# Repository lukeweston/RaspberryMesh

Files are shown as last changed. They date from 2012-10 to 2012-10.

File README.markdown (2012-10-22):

**Raspberry Pi sensor / power supply / LCD / 802.15.4 mesh network expansion board**   
Luke Weston, 2012     

Released as Open Hardware under the CERN Open Hardware License - http://ohwr.org/cernohl  

This Raspberry Pi add-on daughterboard or shield incorporates a 16x2 alphanumeric LCD display (standard HD44780-type display), a visible light sensor, a barometric pressure
and temperature sensor, a smal RGB LED for visual output, and an Atmel ATmega128RFA1 AVR microcontroller with integrated IEEE 802.15.4 mesh network transceiver with support
for IPv6/6LoWPAN. 

A real-time clock with battery backup and a buck-converter voltage regulator allowing a wide input voltage range between 7 and 35 volts to power the Raspberry Pi are also
included. Voltages up to 35V can simply be plugged into the 2.1mm power jack to power the entire system flexibly.

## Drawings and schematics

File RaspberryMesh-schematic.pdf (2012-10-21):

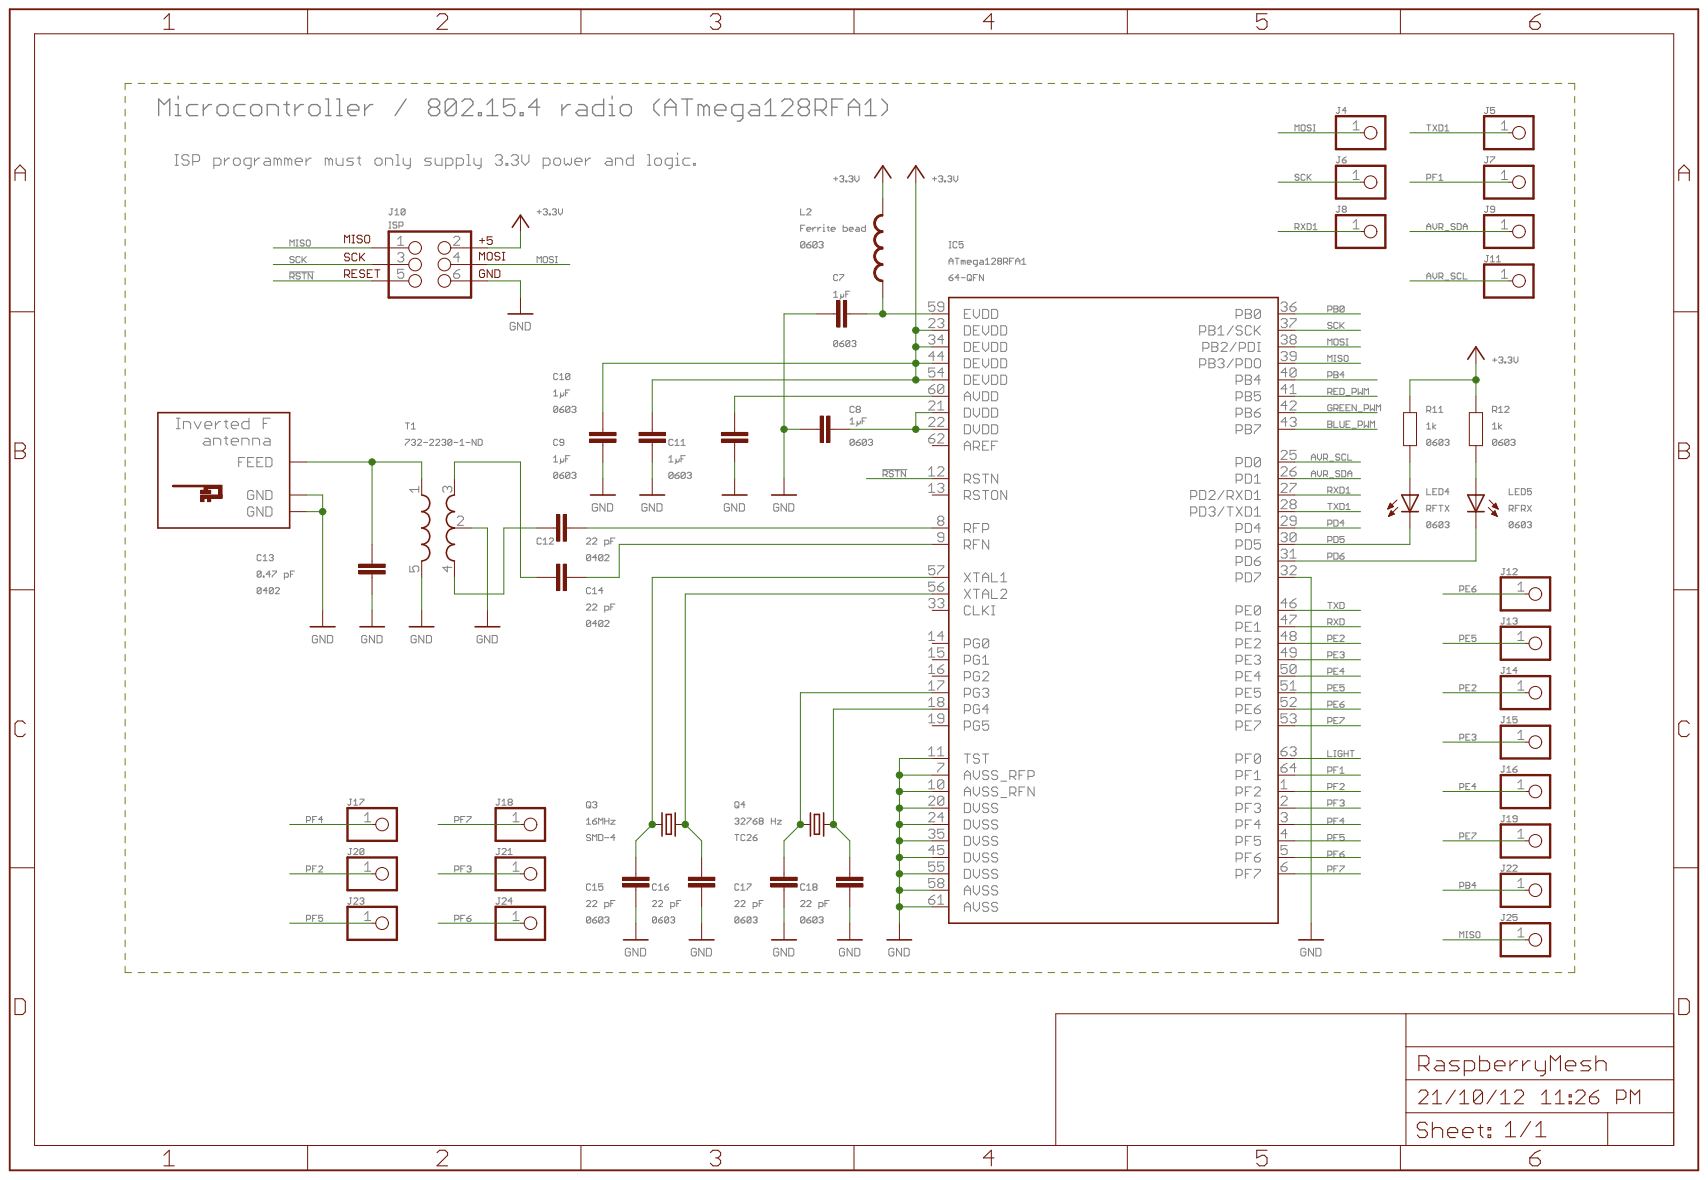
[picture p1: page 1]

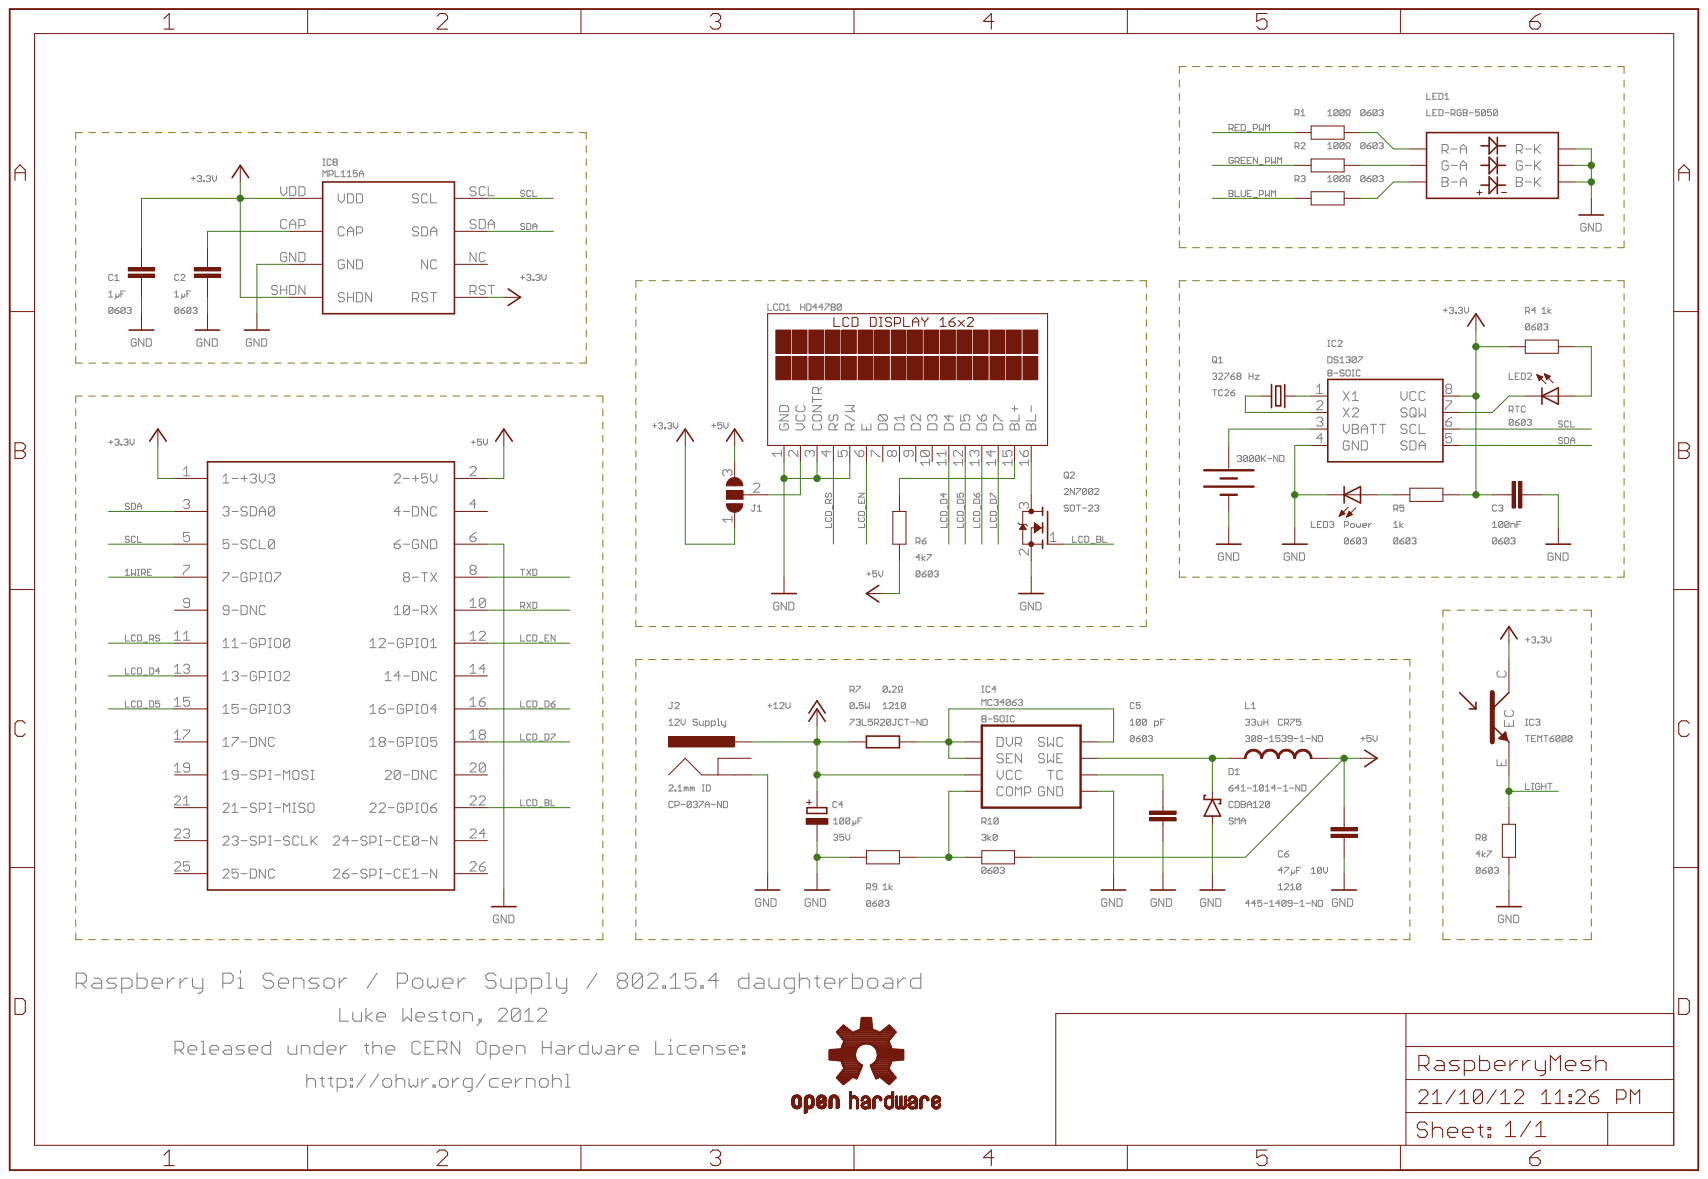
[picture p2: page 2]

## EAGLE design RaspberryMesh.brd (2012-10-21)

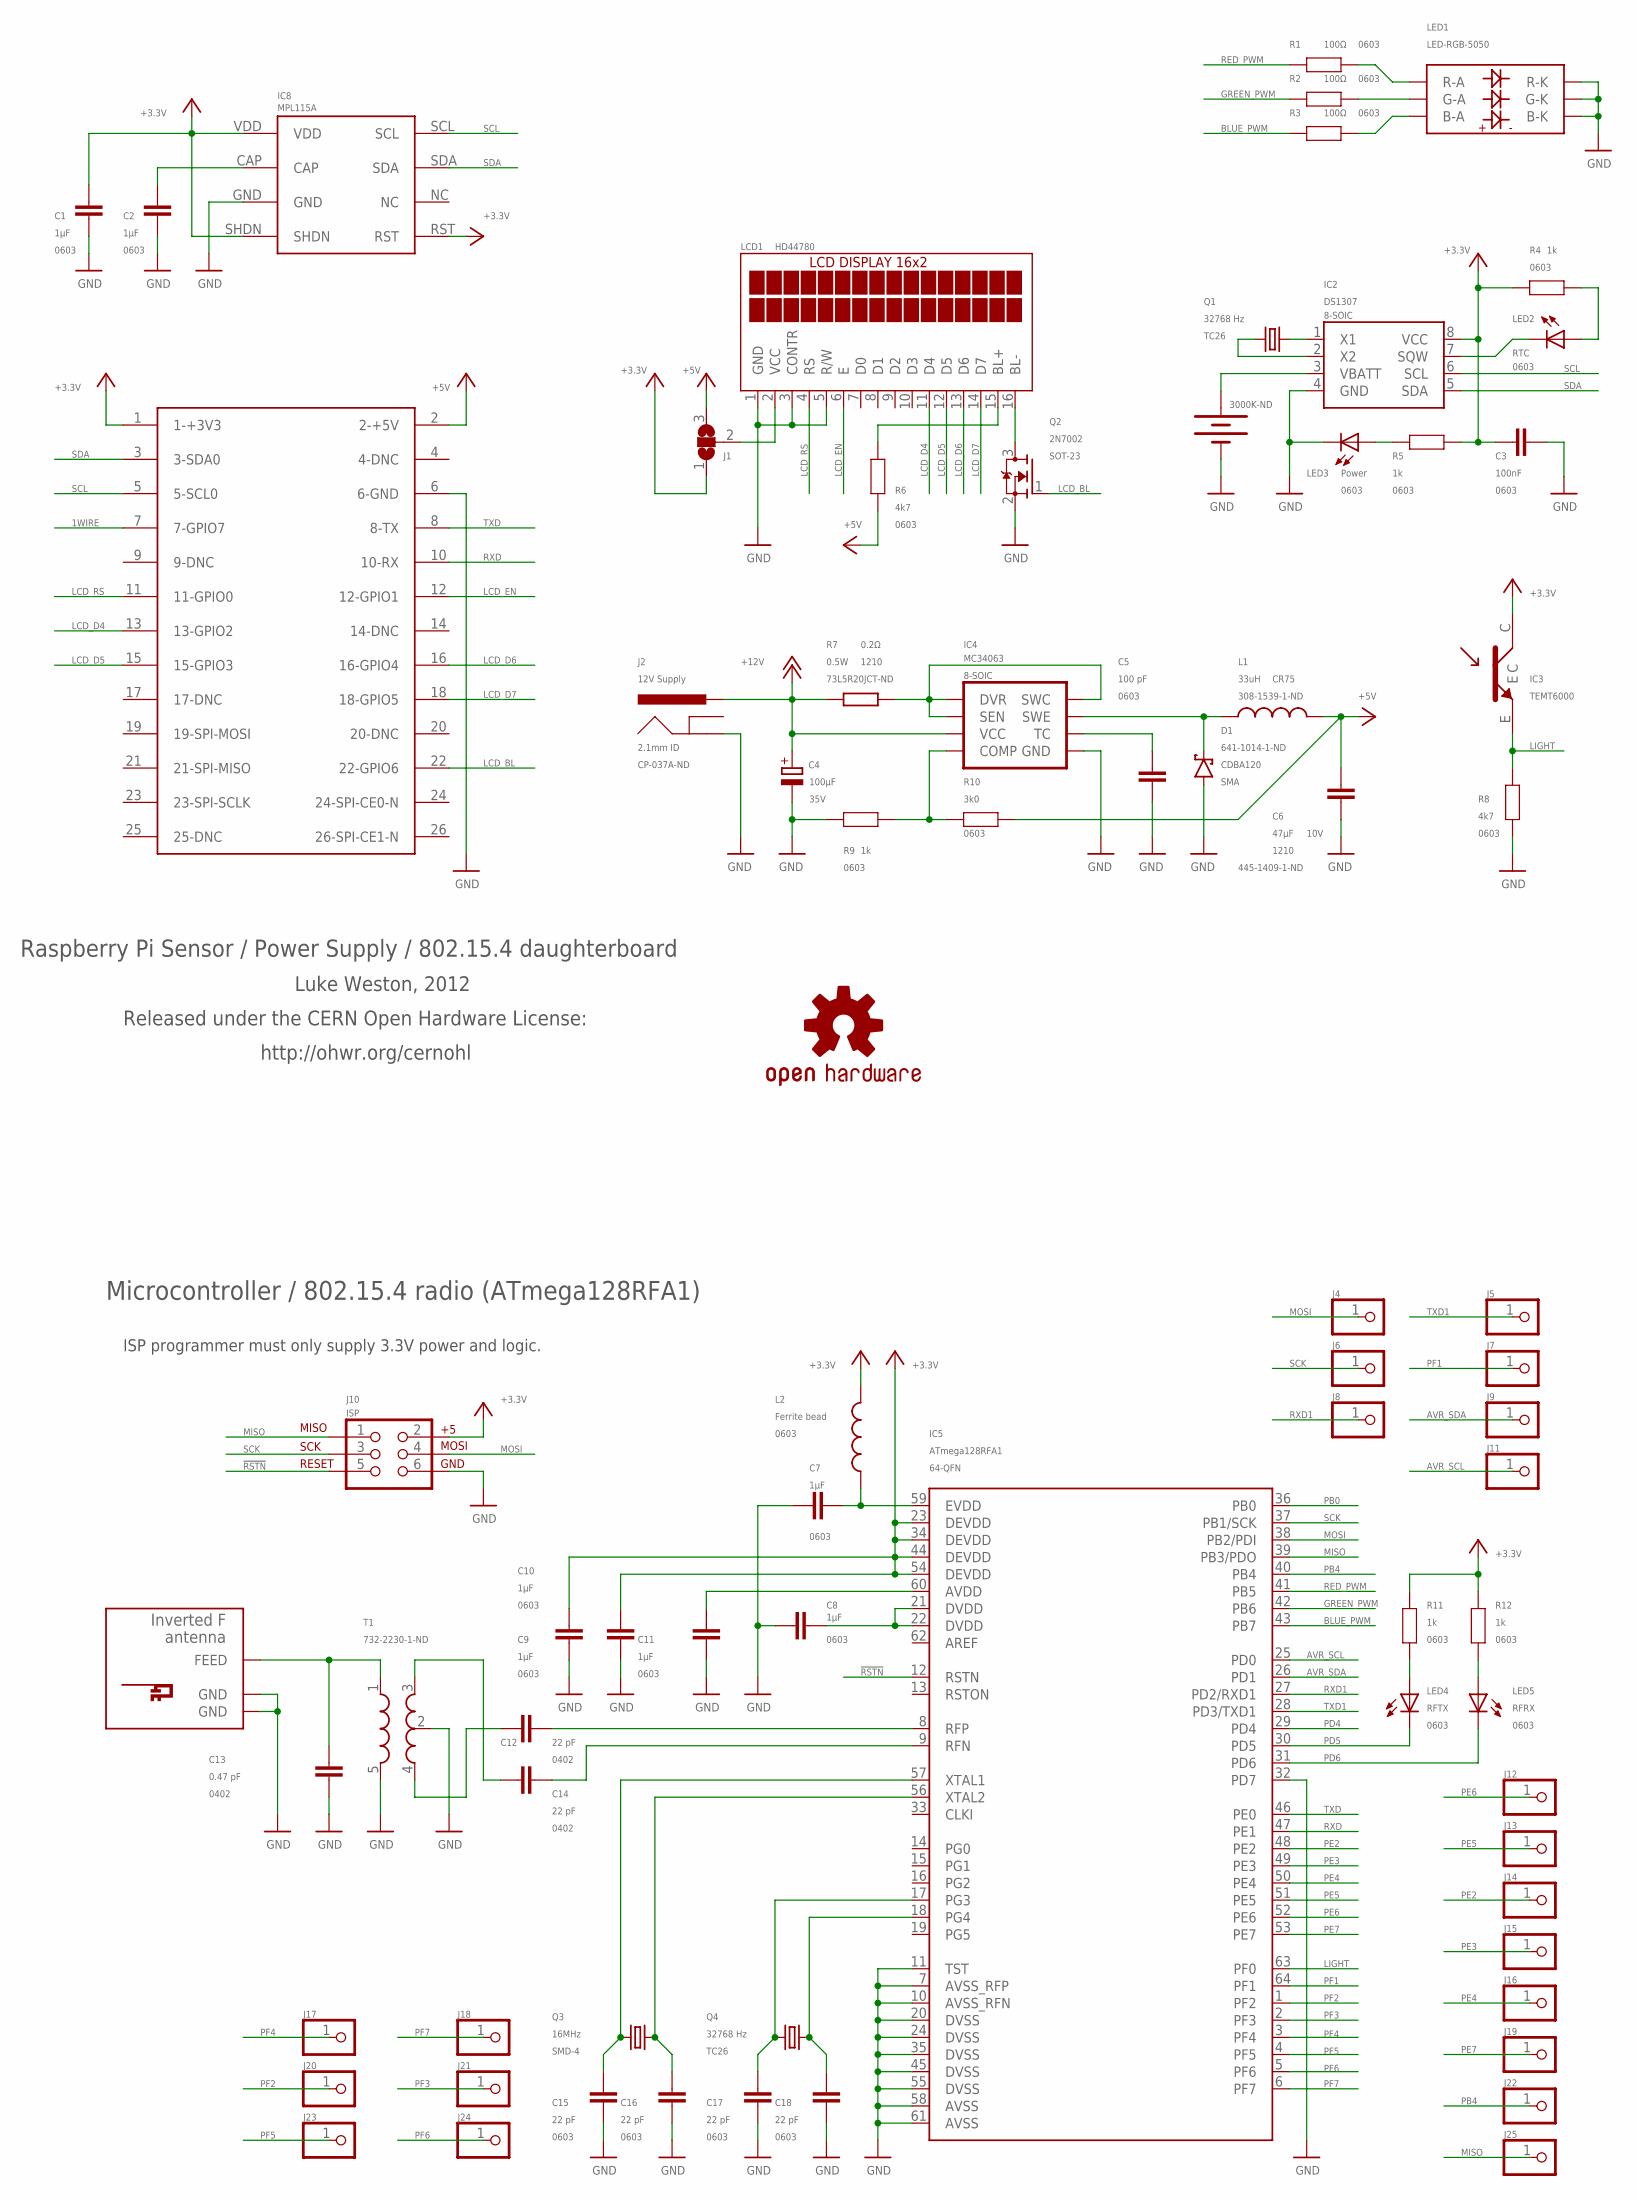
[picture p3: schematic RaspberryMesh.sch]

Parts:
A1: INVERTED_F_ANTENNA+2; DN007+2
B1: 3000K-ND; BATTCON_12MM
C1, C2, C7, C8, C9, C10, C11: 1µF; 0603
C3: 100nF; 0603
C4: 100µF; E2,5-6; VOLTAGE 35V
C5: 100 pF; 0603
C6: 47µF; C1210; VOLTAGE 10V
C12, C14: 22 pF; C0402
C13: 0.47 pF; C0402
C15, C16, C17, C18: 22 pF; 0603
D1: CDBA120; SMA
IC1: MPL115A
IC2: DS1307; SO08
IC3: TEMT6000
IC4: MC34063; SO08@1
IC5: ATmega128RFA1; QFN-64
J1: SJ2W; SJ_2
J2: 12V Supply; POWER_JACK_SLOT
J3: RASPBERRY-PI
J4, J5, J6, J7, J8, J9, J11, J12, J13, J14, J15, J16, J17, J18, J19, J20, J21, J22, J23, J24, J25: PINHD-1X1; 1X01
J10: ISP; 2X3-NS
L1: 33uH; CR75
L2: Ferrite bead; 0603
LCD1: HD44780; LCD_16X2_REAR
LED1: LED-RGB-5050
LED2: RTC; LED-0603
LED3: Power; LED-0603
LED4: RFTX; LED-0603
LED5: RFRX; LED-0603
Q1, Q4: 32768 Hz; CRYSTAL-32KHZ-SMD
Q2: 2N7002; SOT23
Q3: 16MHz; CRYSTAL-SMD-5X3
R1, R2, R3: 100Ω; 0603
R4, R5, R9, R11, R12: 1k; 0603
R6, R8: 4k7; 0603
R7: 0.2Ω; R1210
R10: 3k0; 0603
SY1: OSHW-LOGOS; OSHW-LOGO-S
T1: 732-2230-1-ND; BALUN

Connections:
1WIRE: J3.7 (7-GPIO7)
!RSTN: IC5.12 (RSTN), J10.5
+3V3: C1.2, C3.1, C9.1, C10.1, IC1.RST, IC1.SHDN, IC1.VDD, IC2.8 (VCC), IC3.C, IC5.23 (DEVDD), IC5.34 (DEVDD), IC5.44 (DEVDD), IC5.54 (DEVDD), J1.1, J3.1 (1-+3V3), J10.2, L2.2, R4.2, R5.2, R11.2, R12.2
+5V: C6.1, J1.3, J3.2 (2-+5V), L1.P$2 (2), R6.2, R10.1
+12V: C4.+, IC4.6 (VCC), J2.PWR, R7.1
AVR_SCL: IC5.25 (PD0), J11.1
AVR_SDA: IC5.26 (PD1), J9.1
BLUE_PWM: IC5.43 (PB7), R3.2
GND: A1.GND, A1.GND@1 (GND), B1.GND (-), C1.1, C2.1, C3.2, C4.-, C5.2, C6.2, C7.2, C8.2, C9.2, C10.2, C11.2, C13.2, C15.1, C16.1, C17.1, C18.1, D1.A, IC1.GND, IC2.4 (GND), IC4.4 (GND), IC5.7 (AVSS_RFP), IC5.10 (AVSS_RFN), IC5.11 (TST), IC5.20 (DVSS), IC5.24 (DVSS), IC5.32 (PD7), IC5.35 (DVSS), IC5.45 (DVSS), IC5.55 (DVSS), IC5.58 (AVSS), IC5.61 (AVSS), J2.GND, J3.6 (6-GND), J10.6, LCD1.1 (GND), LCD1.3 (CONTR), LCD1.5 (R/W), LED1.BK (B-K), LED1.GK (G-K), LED1.RK (R-K), LED3.C, Q2.2 (S), R8.1, R9.2, T1.2 (GND), T1.5 (GND)
GREEN_PWM: IC5.42 (PB6), R2.2
LCD_BL: J3.22 (22-GPIO6), Q2.1 (G)
LCD_D4: J3.13 (13-GPIO2), LCD1.11 (D4)
LCD_D5: J3.15 (15-GPIO3), LCD1.12 (D5)
LCD_D6: J3.16 (16-GPIO4), LCD1.13 (D6)
LCD_D7: J3.18 (18-GPIO5), LCD1.14 (D7)
LCD_EN: J3.12 (12-GPIO1), LCD1.6 (E)
LCD_RS: J3.11 (11-GPIO0), LCD1.4 (RS)
LIGHT: IC3.E, IC5.63 (PF0), R8.2
MISO: IC5.39 (PB3/PDO), J10.1, J25.1
MOSI: IC5.38 (PB2/PDI), J4.1, J10.4
unnamed: J1.2, LCD1.2 (VCC)
unnamed: IC4.1 (SWC), IC4.7 (SEN), IC4.8 (DVR), R7.2
unnamed: LCD1.15 (BL+), R6.1
unnamed: IC2.7 (SQW), LED2.C
unnamed: C5.1, IC4.3 (TC)
unnamed: LCD1.16 (BL-), Q2.3 (D)
unnamed: IC4.5 (COMP), R9.1, R10.2
unnamed: LED3.A, R5.1
unnamed: C2.2, IC1.CAP
unnamed: IC2.2 (X2), Q1.X1 (1)
unnamed: IC2.1 (X1), Q1.X2 (2)
unnamed: LED2.A, R4.1
unnamed: B1.PWR@1 (+), IC2.3 (VBATT)
unnamed: C14.2, T1.3 (OUT1)
unnamed: C12.2, T1.4 (OUT2)
unnamed: C16.2, IC5.56 (XTAL2), Q3.3 (2)
unnamed: C15.2, IC5.57 (XTAL1), Q3.1
unnamed: C17.2, IC5.17 (PG3), Q4.X1 (1)
unnamed: C18.2, IC5.18 (PG4), Q4.X2 (2)
unnamed: C8.1, IC5.21 (DVDD), IC5.22 (DVDD)
unnamed: C11.1, IC5.60 (AVDD)
unnamed: A1.FEED, C13.1, T1.1 (IN)
unnamed: C7.1, IC5.59 (EVDD), L2.1
unnamed: C12.1, IC5.8 (RFP)
unnamed: C14.1, IC5.9 (RFN)
unnamed: LED4.A, R11.1
unnamed: LED5.A, R12.1
unnamed: D1.K, IC4.2 (SWE), L1.P$1 (1)
unnamed: LED1.RA (R-A), R1.1
unnamed: LED1.GA (G-A), R2.1
unnamed: LED1.BA (B-A), R3.1
PB0: IC5.36 (PB0)
PB4: IC5.40 (PB4), J22.1
PD4: IC5.29 (PD4)
PD5: IC5.30 (PD5), LED4.C
PD6: IC5.31 (PD6), LED5.C
PE2: IC5.48 (PE2), J14.1
PE3: IC5.49 (PE3), J15.1
PE4: IC5.50 (PE4), J16.1
PE5: IC5.51 (PE5), J13.1
PE6: IC5.52 (PE6), J12.1
PE7: IC5.53 (PE7), J19.1
PF1: IC5.64 (PF1), J7.1
PF2: IC5.1 (PF2), J20.1
PF3: IC5.2 (PF3), J21.1
PF4: IC5.3 (PF4), J17.1
PF5: IC5.4 (PF5), J23.1
PF6: IC5.5 (PF6), J24.1
PF7: IC5.6 (PF7), J18.1
RED_PWM: IC5.41 (PB5), R1.2
RXD: IC5.47 (PE1), J3.10 (10-RX)
RXD1: IC5.27 (PD2/RXD1), J8.1
SCK: IC5.37 (PB1/SCK), J6.1, J10.3
SCL: IC1.SCL, IC2.6 (SCL), J3.5 (5-SCL0)
SDA: IC1.SDA, IC2.5 (SDA), J3.3 (3-SDA0)
TXD: IC5.46 (PE0), J3.8 (8-TX)
TXD1: IC5.28 (PD3/TXD1), J5.1

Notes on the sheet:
Raspberry Pi Sensor / Power Supply / 802.15.4 daughterboard
Luke Weston, 2012
Released under the CERN Open Hardware License:
http://ohwr.org/cernohl
ISP programmer must only supply 3.3V power and logic.
Microcontroller / 802.15.4 radio (ATmega128RFA1)

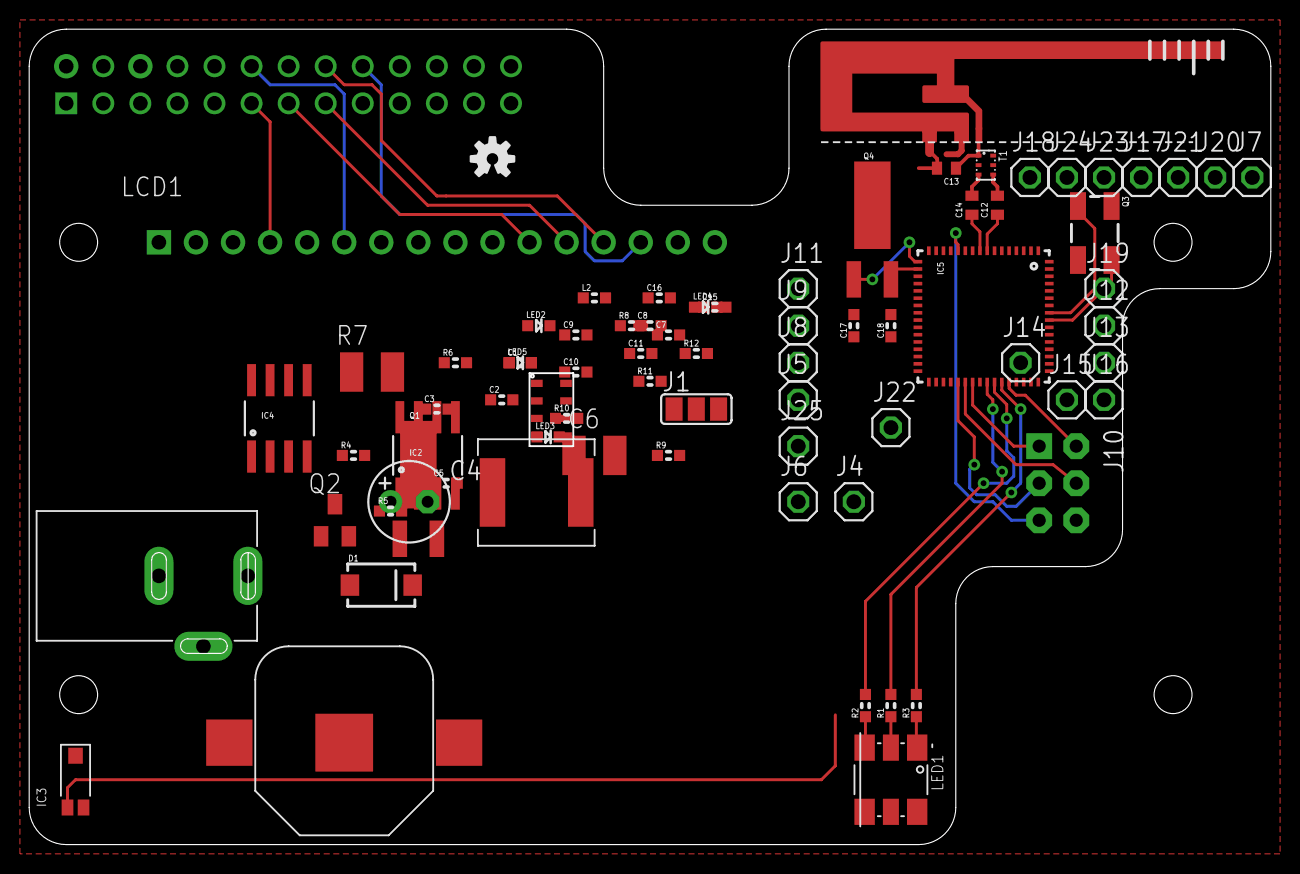
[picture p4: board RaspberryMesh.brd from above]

Board: 2 copper layers, 85.1 x 55.9 mm, 77 parts (0 on the bottom side), 74 nets.
